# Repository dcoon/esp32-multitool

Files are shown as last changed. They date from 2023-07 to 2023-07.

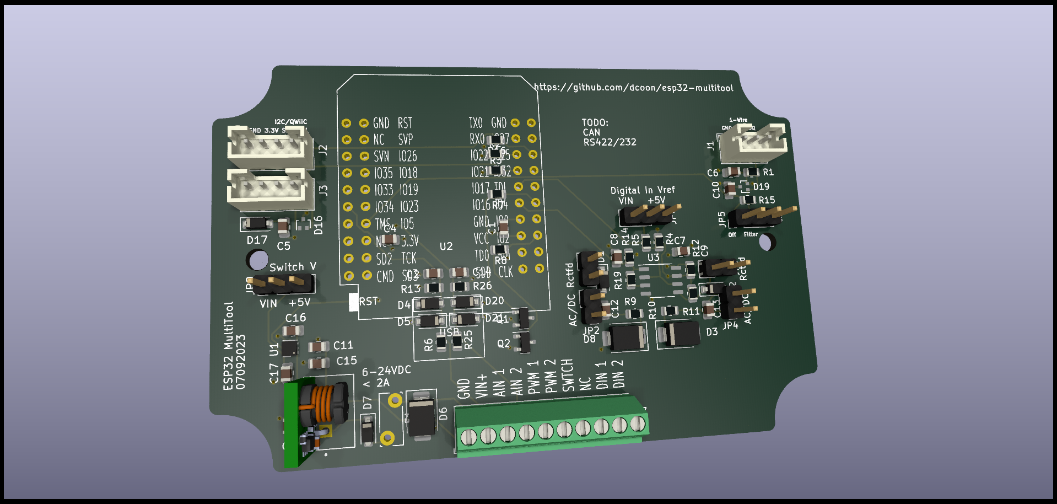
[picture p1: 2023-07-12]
hardware/esp32-multitool.png

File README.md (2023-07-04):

# ESP32 Multitool

ESP32 Multitool is an I/O board for ESP32 microcontroller based projects.  It is designed for IoT projects on a boat but can be used in automotive, RV, and home environments.  It is designed to be inexpensive, robust, energy efficient, and easy to use.  It supports firmware from multiple open source projects including ESPHome, ESPSense, and Platformio.

## Features

- 3x Analog Inputs
	- +0-30VDC
	- Measure voltage or resistance
- 3x PWM/Switch Outputs
	- Configurable voltage from VIN, +5V, and External
	- 1A current per channel
- 1x Pulse/Tachometer Input
- 1x Digital Potentiometer
- CAN/N2K 
- RS422/NMEA 0183
- 1-Wire
- I2C
	- Qwiic and Adafruit compatible I2C connector
- SPI
- Wifi/BLE
- Power
	- +5 - 30VDC Input
	- OVP, RV, and ESD Protection
- Software Compatibility
	- ESPHome
	- ESPSense
	- Platformio

## Examples

TBD

### Tank Level Monitor
### Engine Monitor
### Fan Controller
### LED Dimmer

### More
- Refridgerator Controller
- Barometer & Lightning Detector

## Acknowledgements

### Sailorhat

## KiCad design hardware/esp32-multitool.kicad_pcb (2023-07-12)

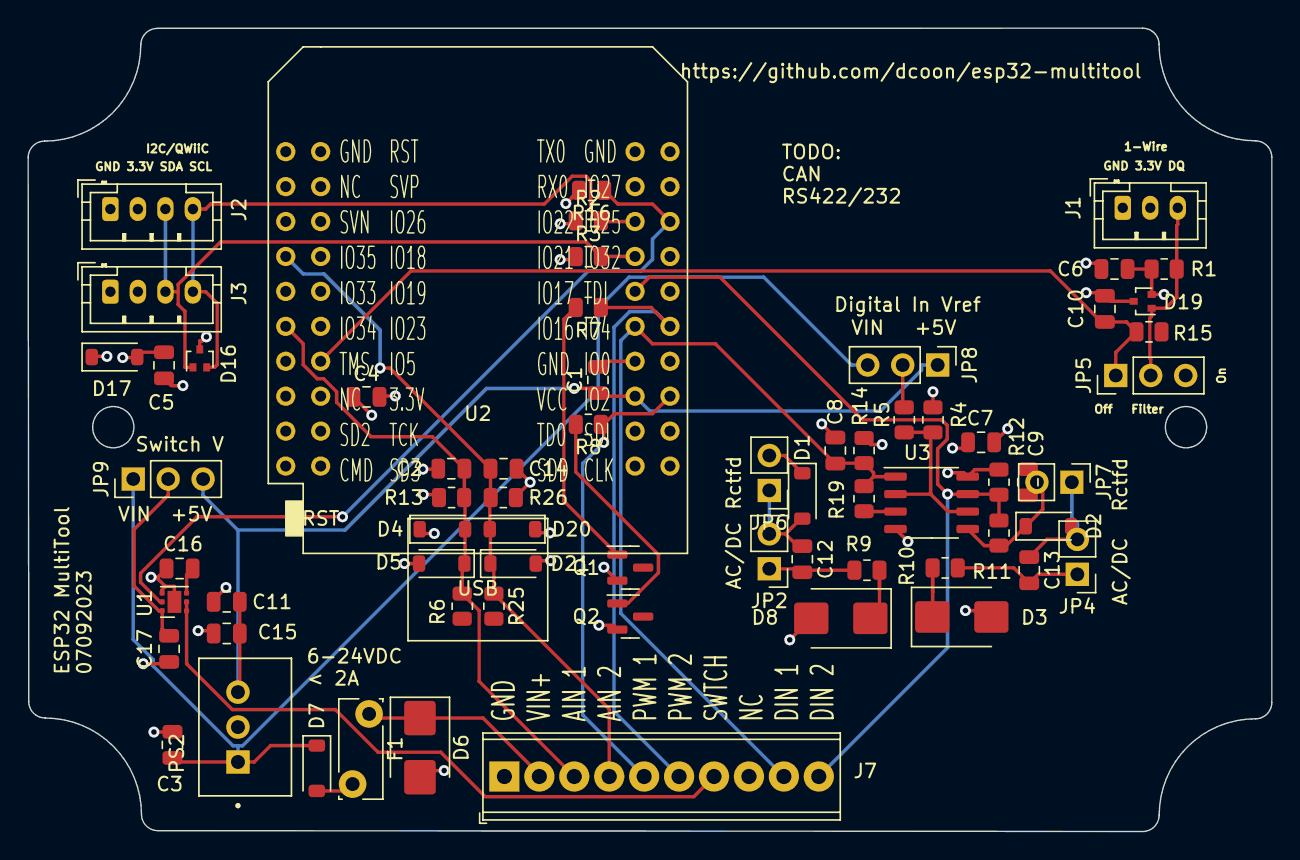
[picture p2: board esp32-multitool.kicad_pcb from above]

Board: 4 copper layers, 90.4 x 58.4 mm, 67 parts (0 on the bottom side), 32 nets.

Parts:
C1, C2, C4, C5, C6, C7, C8, C9, C14: 1uF; C_0805_2012Metric
C3: 10uF/50V; C_0805_2012Metric
C10: 1nF; C_0805_2012Metric
C11, C15: 47uF/16V; C_0805_2012Metric
C12, C13: 22nF/30V; C_0805_2012Metric
C16: 4700p; C_0805_2012Metric
C17: 4.7uF/30V; C_0805_2012Metric
D1, D2, D4, D5, D7, D20, D21: D_SCHOTTKY_30V; D_SOD-123
D3, D6, D8: D_TVS_30V; D_SMB
D16, D19: RCLAMP0502B; SOT-416
D17: D_TVS_3V3; D_SOD-123
F1: Fuse; Fuse_Bourns_MF-RG300
J1: Conn_01x03/1Wire; JST_PH_B3B-PH-K_1x03_P2.00mm_Vertical
J2, J3: Conn_01x04/QWiiC; JST_PH_B4B-PH-K_1x04_P2.00mm_Vertical
J7: Conn_01x09; TerminalBlock_Phoenix_MPT-0,5-10-2.54_1x10_P2.54mm_Horizont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
JP2, JP4, JP6, JP7: Jumper_2_Bridged; PinHeader_1x02_P2.54mm_Vertical
JP5, JP9: Jumper_3_Bridged12; PinHeader_1x03_P2.54mm_Vertical
JP8: Jumper_2_Open; PinHeader_1x03_P2.54mm_Vertical
PS2: TPSM84205EAB
Q1, Q2: AO3400A; SOT-23
R1: 4.7k; R_0805_2012Metric
R2, R3: 2.7k; R_0805_2012Metric
R4, R5: 10k; R_0805_2012Metric
R6, R9, R10, R25: 100k; R_0805_2012Metric
R7, R8: 100; R_0805_2012Metric
R11, R13, R19, R26: 1M; R_0805_2012Metric
R12, R14: 5.1K; R_0805_2012Metric
R15: 150; R_0805_2012Metric
R16: 10k/30V; R_0805_2012Metric
U1: TPS22810DRV; WSON-6-1EP_2x2mm_P0.65mm_EP1x1.6mm
U2: wemos_mini_esp32; ESP32_mini
U3: LM393; SOP-8_3.9x4.9mm_P1.27mm

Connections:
+3.3V: C4.1, C5.1, C6.1, C7.1, D4.1 (K), D17.2 (A2), D19.2 (K2), D20.1 (K), J1.2, J2.2, J3.2, R1.2, R2.1, R3.1, R12.1, R14.1, U2.16 (3V3), U3.8 (V+)
+5V: C1.1, C11.1, C15.1, JP8.1 (A), JP9.3 (B), PS2.3 (VOUT), U2.35 (VCC_(USB))
/1WIRE_DQ: C10.1, JP5.1 (A), R15.1, U2.14 (IO_05/D8)
/1wire/DQ: D19.1 (K1), J1.3, JP5.2 (C), R1.1
/AIN1: C2.1, D4.2 (A), D5.1 (K), J7.3, R6.1, R13.1, U2.11 (IO_34)
/AIN2: C14.1, D20.2 (A), D21.1 (K), J7.4, R25.1, R26.1, U2.7 (IO_35)
/DIN1: C8.1, J7.9, R14.2, R19.2, U2.31 (IO_16/D4), U3.1
/DIN2: C9.1, J7.10, R11.2, R12.2, U2.29 (IO_17/D3), U3.7
/DIN_LINE1: D8.1 (A1), R9.2
/DIN_LINE2: D3.1 (A1), R10.2
/I2C_SCL: D16.2 (K2), J2.4, J3.4, R2.2, U2.25 (IO_22/D1/SCL)
/I2C_SDA: D16.1 (K1), J2.3, J3.3, R3.2, U2.27 (IO_21/D2/SDA)
/PWM1: J7.5, R8.1, U2.36 (IO_02)
/PWM2: J7.6, R7.1, U2.32 (IO_04)
/SWITCH1: R16.1, U1.5 (EN/UVLO), U2.26 (IO_25)
/SWITCH_LINE1: J7.7, U1.1 (VOUT), U1.2 (QOD)
/VIN: D6.1 (A1), F1.1, J7.2
/digital_in/DIN_VREF: R4.2, R5.1, U3.2 (-), U3.6 (-)
GND: C1.2, C2.2, C3.2, C4.2, C5.2, C6.2, C7.2, C8.2, C9.2, C10.2, C11.2, C14.2, C15.2, C16.2, C17.2, D3.2 (A2), D5.2 (A), D6.2 (A2), D8.2 (A2), D16.3 (A), D17.1 (A1), D19.3 (A), D21.2 (A), J1.1, J2.1, J3.1, J7.1, PS2.2 (GND), Q1.2 (S), Q2.2 (S), R5.2, R13.2, R16.2, R26.2, U1.4 (GND), U1.7 (GND), U2.1 (GND), U2.22 (GND), U2.33 (GND), U3.4 (V-)
unnamed: C12.1, D1.2 (A), JP2.2 (B), JP6.1 (A)
unnamed: D1.1 (K), JP6.2 (B), R19.1, U3.3 (+)
unnamed: C13.1, D2.2 (A), JP4.2 (B), JP7.1 (A)
unnamed: D2.1 (K), JP7.2 (B), R11.1, U3.5 (+)
unnamed: D7.2 (A), F1.2
unnamed: C12.2, JP2.1 (A), R9.1
unnamed: C13.2, JP4.1 (A), R10.1
unnamed: JP8.2 (C), R4.1
unnamed: C17.1, JP9.2 (C), U1.6 (VIN)
unnamed: Q1.1 (G), R7.2
unnamed: Q2.1 (G), R8.2
unnamed: C16.1, U1.3 (CT)
VPP: C3.1, D7.1 (K), JP8.3 (B), JP9.1 (A), PS2.1 (VIN)

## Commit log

2022-09-04 Initial schematic and board layout
    [1wire.kicad_sch, analog_in.kicad_sch, analog_io.kicad_sch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]
2023-06-14 renamed multitool to hardware
    [1wire.kicad_sch, analog_in.kicad_sch, analog_io.kicad_sch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]
2023-07-04 block refactoring
    [1wire.kicad_sch, AOZ1280CI.kicad_pcb, AOZ1280CI.kicad_sch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]
2023-07-08 moving subsheets to blocks
    [1wire.kicad_sch, digital_io.kicad_sch, esp32-multitool.kicad_pcb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]
2023-07-12 Added 3D models and ran freerouting
    [1wire.kicad_sch, AOZ1280CI.kicad_sch, LM393.kicad_sch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]

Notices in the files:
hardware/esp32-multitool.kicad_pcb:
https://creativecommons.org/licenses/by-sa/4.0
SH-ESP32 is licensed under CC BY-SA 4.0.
